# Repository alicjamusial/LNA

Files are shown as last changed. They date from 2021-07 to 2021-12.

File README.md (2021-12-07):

# Lynx - LNA with filter for 400-440 MHz

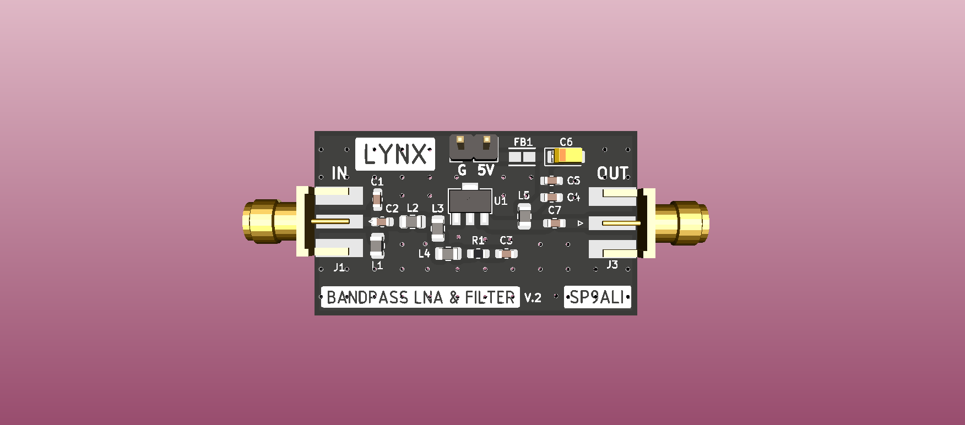
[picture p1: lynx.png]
pcb


### ◾ About the project

**Lynx** is an LNA with a filter with two SMA connectors. It was designed for 400-400 MHz (UHF satellite amateur band) by default, but by changing components' values it can be tuned to every chosen frequency. It contains the amplifier (with PGA-103+ as the main component) and the bandpass Chelbyshev filter (shunt first, 2nd order).
 
Gerber files for version 2.0 of Lynx is available [in the releases section](https://github.com/alicjamusial/LNA/releases/tag/release-2.0.0). 

The board was designed using [KiCad](https://kicad.org/) (version: `5.99.0-7233-g6a28d6af27`).

### ◾ Usage
- **Very important!** Order PCB with **0.6mm** thickness and 1oz copper weight.
- Lynx requires connection of 5V and GND.
- It would be best to connect Lynx as close to the antenna as possible.

### ◾ Parameters
According to the measurements, in range 400-440 MHz Lynx should provide gain around 16-20 dB.

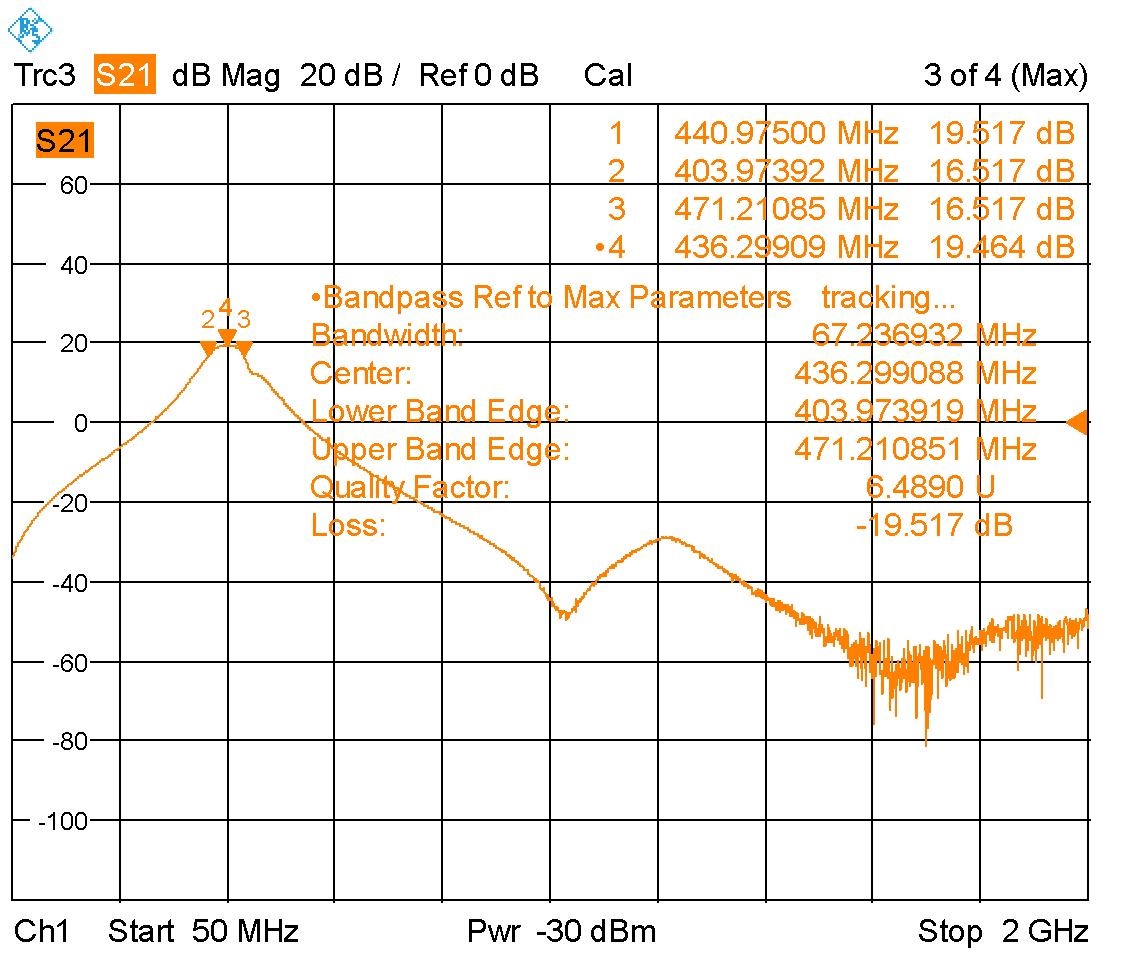
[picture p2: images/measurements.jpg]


### ◾ License
Lynx is available on Creative Commons Attribution Share Alike 4.0 International license (more in [license file](LICENSE.txt)). You are free to use it, modify it and produce as many of your own boards as you need :)

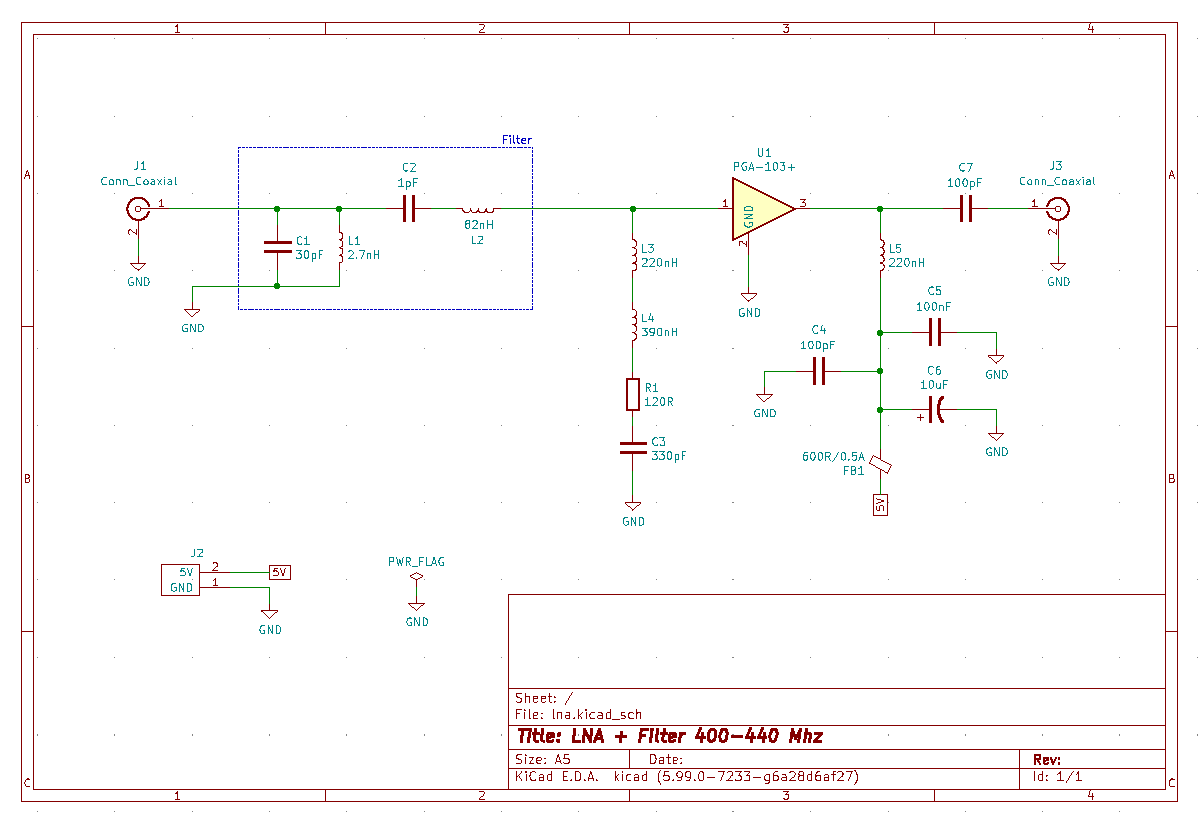
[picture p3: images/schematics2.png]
schema

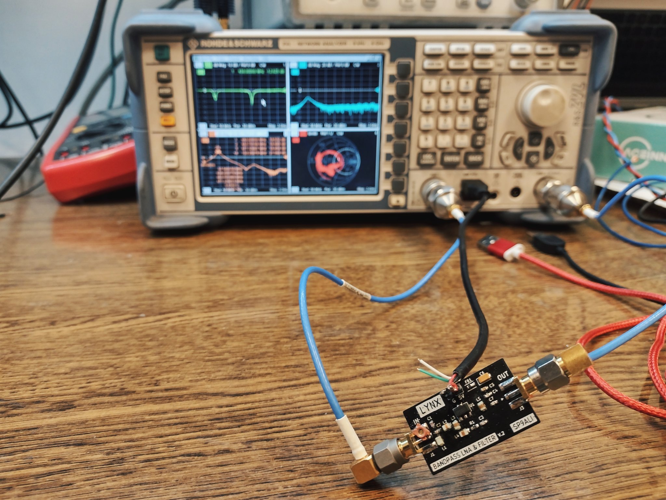
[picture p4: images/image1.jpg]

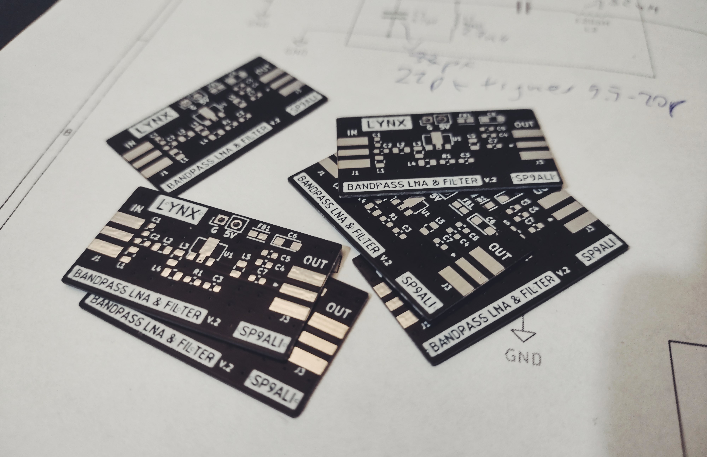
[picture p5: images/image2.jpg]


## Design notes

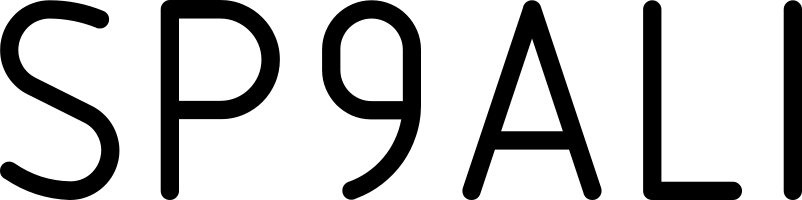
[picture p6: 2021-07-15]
images/imgs/sign.png

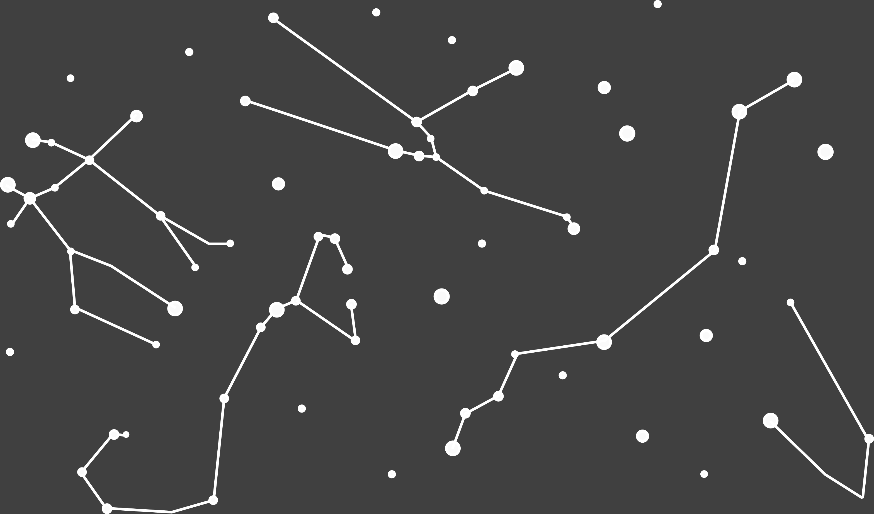
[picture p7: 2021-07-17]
images/BACKGROUND.png

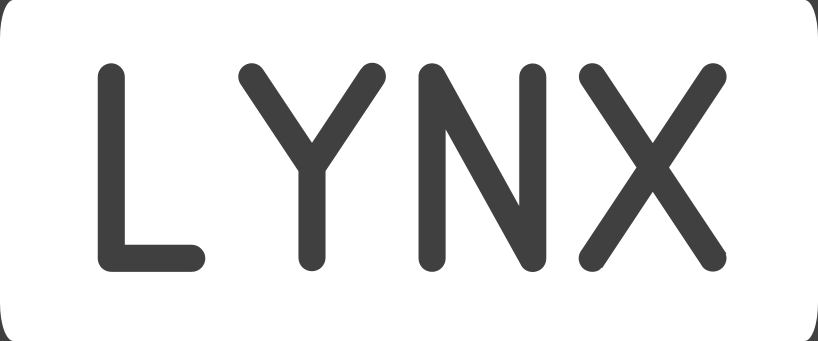
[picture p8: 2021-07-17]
images/NAME.png

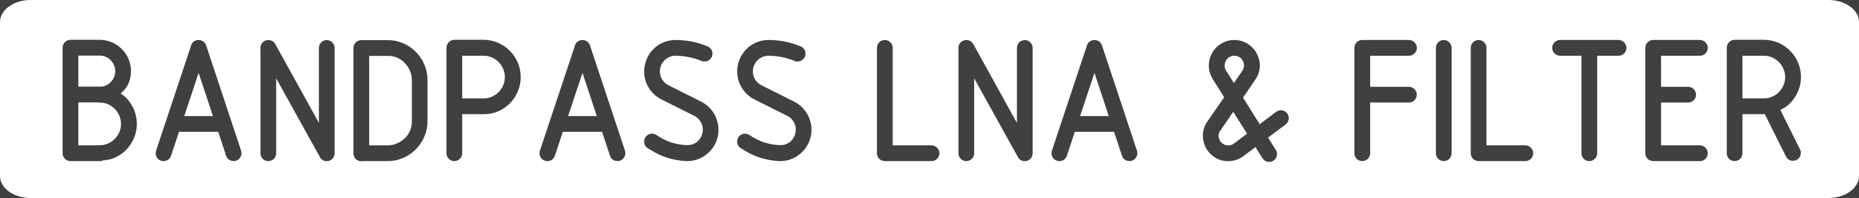
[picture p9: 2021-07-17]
images/LNA.png

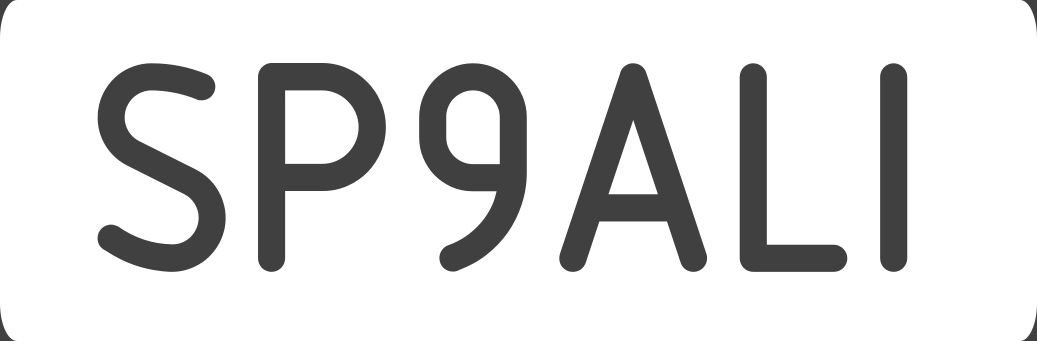
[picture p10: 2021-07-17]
images/SIGN.png

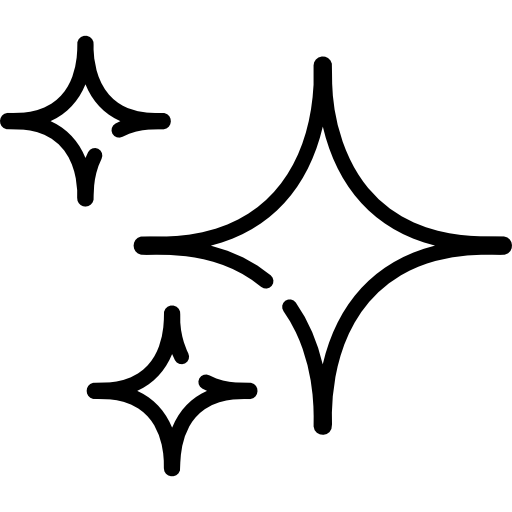
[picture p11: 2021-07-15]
images/imgs/shining.png

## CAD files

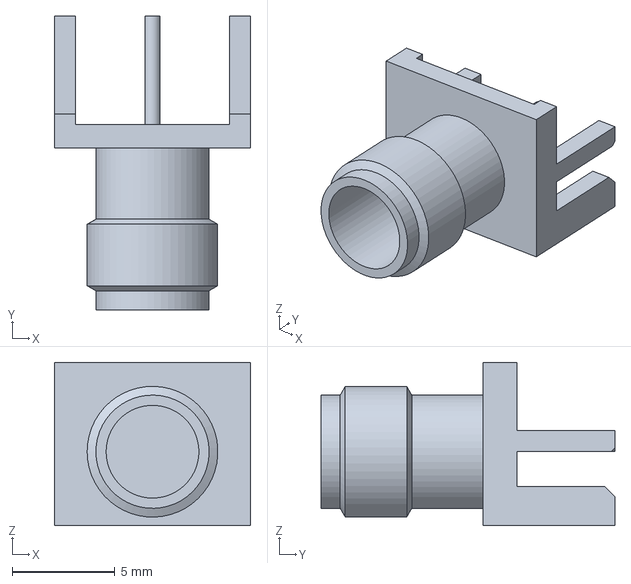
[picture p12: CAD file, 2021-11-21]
lna/models/SMA_Board_Edge_Molex_732511150.step
9.53 x 14.3 x 7.93 mm

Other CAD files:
lna/models/SMA_Board_Edge_Molex_732511150.obj
lna/models/SMA_Board_Edge_Molex_732511150.stl

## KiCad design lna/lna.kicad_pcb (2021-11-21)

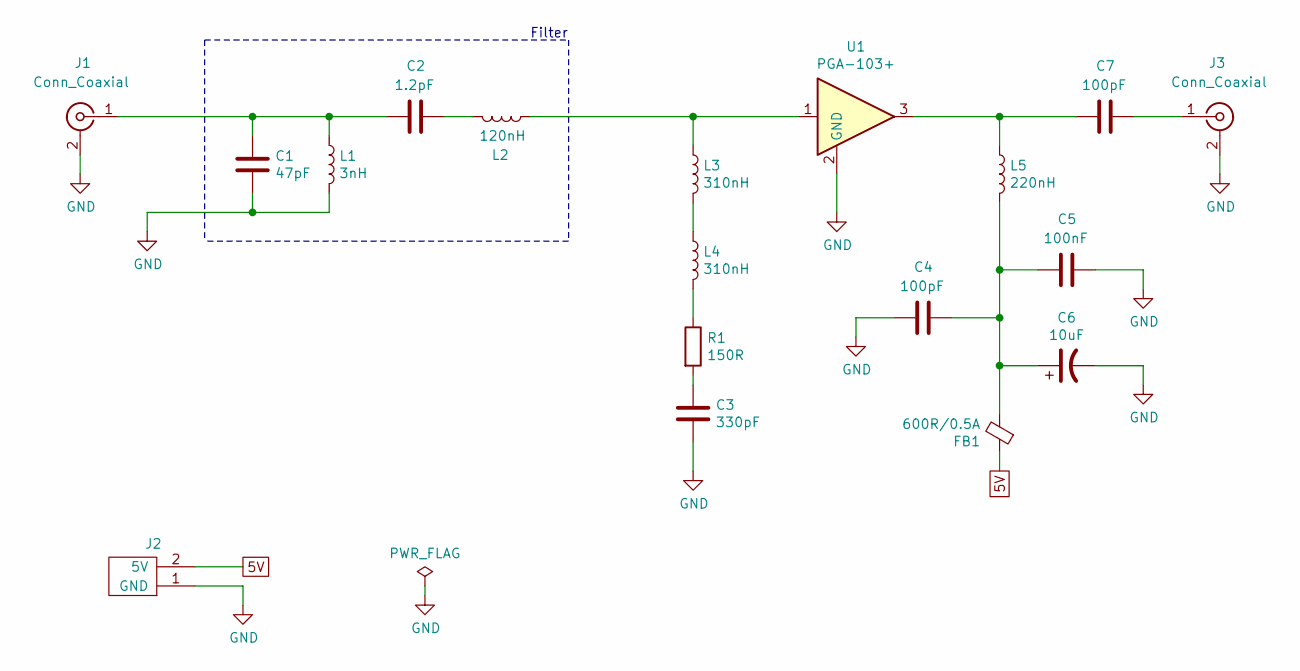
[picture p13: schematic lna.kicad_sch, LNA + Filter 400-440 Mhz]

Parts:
C1: 47pF; C_0603_1608Metric
C2: 1.2pF; C_0603_1608Metric
C3: 330pF; C_0603_1608Metric
C4, C7: 100pF; C_0603_1608Metric
C5: 100nF; C_0603_1608Metric
C6: 10uF; CP_EIA-3216-18_Kemet-A
FB1: 600R/0.5A; Murata-BLM18-0.15-t0.8-0-0-IPC_A
J1, J3: Conn_Coaxial; SMA_Amphenol_132289_EdgeMount
J2: V5-GND; PinHeader_1x02_P2.54mm_Vertical
L1: 3nH; L_0805_2012Metric
L2: 120nH; L_0805_2012Metric
L3, L4: 310nH; L_0805_2012Metric
L5: 220nH; L_0805_2012Metric
R1: 150R; R_0603_1608Metric
U1: PGA-103+; SOT-89-3

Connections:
5V: FB1.1, J2.2 (5V)
GND: C1.2, C3.2, C4.1, C5.2, C6.2, J1.2 (Ext), J2.1 (GND), J3.2 (Ext), L1.2, U1.2 (GND)
unnamed: C1.1, C2.1, J1.1 (In), L1.1
unnamed: C2.2, L2.2
unnamed: C3.1, R1.2
unnamed: C4.2, C5.1, C6.1, FB1.2, L5.2
unnamed: C7.1, L5.1, U1.3
unnamed: C7.2, J3.1 (In)
unnamed: L2.1, L3.1, U1.1
unnamed: L3.2, L4.1
unnamed: L4.2, R1.1

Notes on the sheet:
Filter

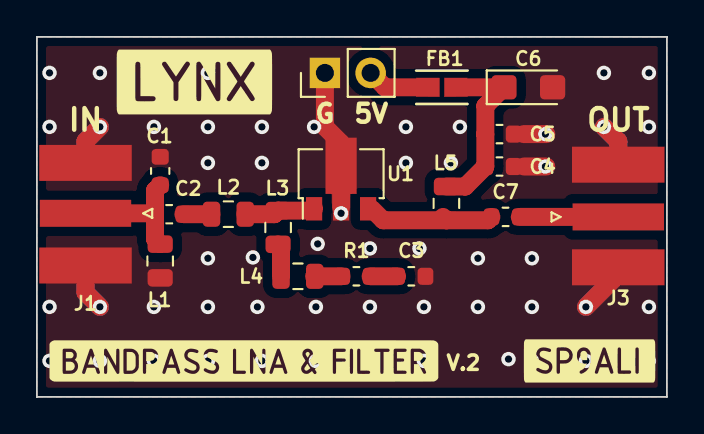
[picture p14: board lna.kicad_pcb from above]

Board: 2 copper layers, 35.0 x 20.0 mm, 18 parts (0 on the bottom side), 11 nets.

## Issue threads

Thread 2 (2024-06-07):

Question about the design of bandpass

shenzihang, 2024-06-07:
Hello, I am trying to simulate a bandpass filter at the input, but the frequency response is not very good. I would like to know what the reason for this might be.
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

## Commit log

2021-07-14 Repo init
    [lna.kicad_pcb, lna.kicad_sch]
2021-07-14 Start LNA project
    [lna.kicad_pcb, lna.kicad_sch]
2021-07-15 PCB part 1
    [lna.kicad_pcb, lna.kicad_sch]
2021-07-15 Add ferrite bead
    [lna.kicad_sch]
2021-07-15 Final v1
    [lna.kicad_pcb, lna.kicad_sch]
2021-07-15 Add some fixes
    [lna.kicad_pcb, lna.kicad_sch]
2021-07-15 Refill zones
    [lna.kicad_pcb]
2021-07-15 Solid zones
    [lna.kicad_pcb]
2021-07-17 LNA images
    [lna.kicad_pcb]
2021-07-17 Add so many holes
    [lna.kicad_pcb]
2021-07-17 Add 3D models for SMA
    [lna.kicad_pcb]
2021-08-16 Gerbers v2
    [lna-B_Cu.gbr, lna-B_Mask.gbr, lna-B_Paste.gbr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]
2021-11-21 Remove not needed files
    [lna-B_Cu.gbr, lna-B_Mask.gbr, lna-B_Paste.gbr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]
2021-11-21 Add proper values of components & update readme
    [lna.kicad_sch]
2021-11-21 Add proper component value
    [lna.kicad_sch]
2021-11-21 Add schematics
